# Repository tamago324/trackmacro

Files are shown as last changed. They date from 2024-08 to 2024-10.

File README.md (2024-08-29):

# trackmacro

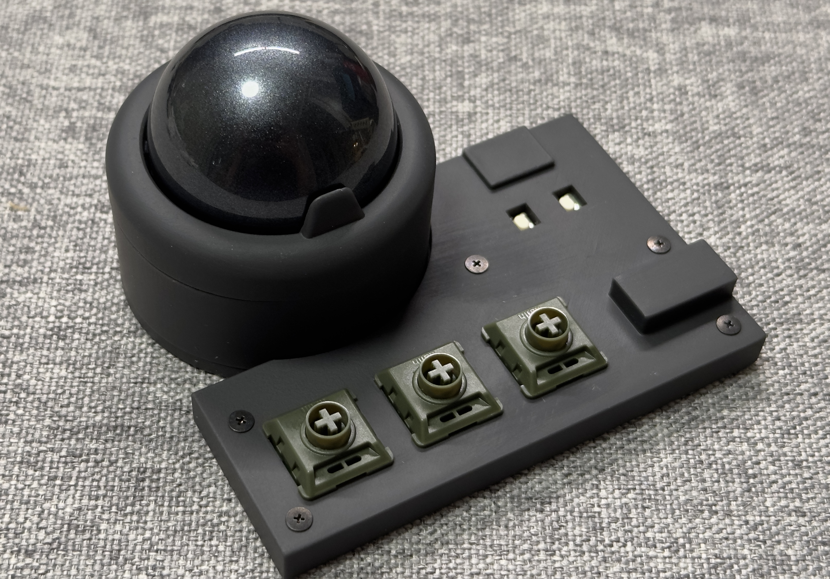
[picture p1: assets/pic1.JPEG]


> NOTE: KiCad 7 を使用しています

* [monkeypad/pmw3360-breakout](https://github.com/monkeypad/pmw3360-breakout) を使用したトラックボール付きのマクロパッド
* キーボードに載せるお試しで作ったもので、以下の要件を満たすものを作った
    * monkeypad/pmw3360-breakout を使う
        * ピンソケットを使用して、ブレークアウトボードは使い回せるようにする
    * RP2040-Zero を使う
        * PCBの裏にはんだ付けする
            * pmw3360-breakout のセンサの高さが一番高くなるため、裏に配置できた
    * 分割キーボードとして機能させる
    * Chocソケットを使う
        * そのためにトッププレートとボトムプレートをスペーサーとねじで止める構造にする
    * ボールケース
        * GameBall のボールを使ったケースを作成する (38mm)
        * 使い回せるような形状にする
        * ベアリングを使う
* [ファームウェア](https://github.com/tamago324/keyboard-firmwares/tree/master/keyboards/trackmacro)

## 使用している部品

|部品|リンク|備考|
|---|---|---|
|PMW3360ブレークアウトボード|[monkeypad/pmw3360-breakout](https://github.com/monkeypad/pmw3360-breakout)|Booth で購入したら、ピンヘッダーもついていたけど、おそらく[これ](https://www.hirosugi-net.co.jp/shop/c/c12103211/)|
|ピンソケット 8ピン|https://www.hirosugi-net.co.jp/shop/c/c12111211/|FSR-41085-08 / 8.5mmのものを使用する|
|スペーサー M2 5mm|https://www.hirosugi-net.co.jp/shop/c/c10141012/|トッププレートとボトムプレートを止めるために使用する|
|ねじ M2 3mm|https://wilco.jp/products/F/FX-EB.html#page3|トッププレートとボトムプレートを止めるために使用する|
|タッピングネジ M2 8mm|https://wilco.jp/products/F/FPP-N.html|FPP-0000N / ボトムプレートとボールケースを止めるために使用する。JLCPCBのレジンに使えるタッピングネジ|
|RP2040-Zero|||
|ダイオード|||
|chocソケット|||
|TRRSソケット|||

### ボールケース関連

|部品|リンク|備考|
|---|---|---|
|ベアリング|https://amzn.asia/d/8OED4Yl|DDL-520ZZW52 / 内径2mm、外形5mm、幅2.5mm|
|ねじ M2 8mm||なべ小ねじならなんでもOK (頭径3.5mm、高さ1.3)|
|ナット M2||1種のナットを使っている|
|磁石 3x2mm|https://amzn.asia/d/gBrgy0N|ボールケースの上下に瞬間接着剤 (アロンアルフア EXTRA 速効多用途) でつけている|

## 3Dプリント

* JLCPCB の3Dプリントを使う想定
* stl 内の stl ファイルを SLA(Resin) で発注する

## LICENSE

<br />この 作品 は <a rel="license" href="http://creativecommons.org/licenses/by-nc/4.0/">クリエイティブ・コモンズ 表示 - 非営利 4.0 国際 ライセンス</a>の下に提供されています。

> 表示 — あなたは 適切なクレジットを表示し、ライセンスへのリンクを提供し、変更があったらその旨を示さなければなりません。これらは合理的であればどのような方法で行っても構いませんが、許諾者があなたやあなたの利用行為を支持していると示唆するような方法は除きます。
>
> 非営利 — あなたは営利目的でこの資料を利用してはなりません。

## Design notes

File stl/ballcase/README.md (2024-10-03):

## ボールケース

* ベアリングの位置は20度
* STLファイル
  * ボールサイズ34mm
    * 34_bottom.stl
    * 34_top.stl
  * ボールサイズ36mm
    * 36_bottom.stl
    * 36_top.stl
  * ボールサイズ38mm
    * 38_bottom.stl
    * 38_top.stl

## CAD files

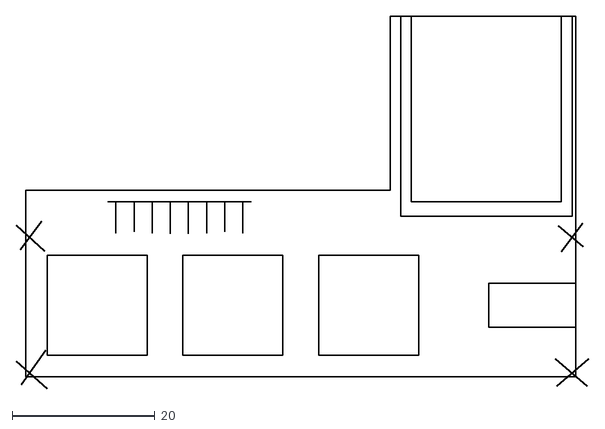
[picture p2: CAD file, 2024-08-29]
dxf/pcb_support.dxf
80.2 x 52.2

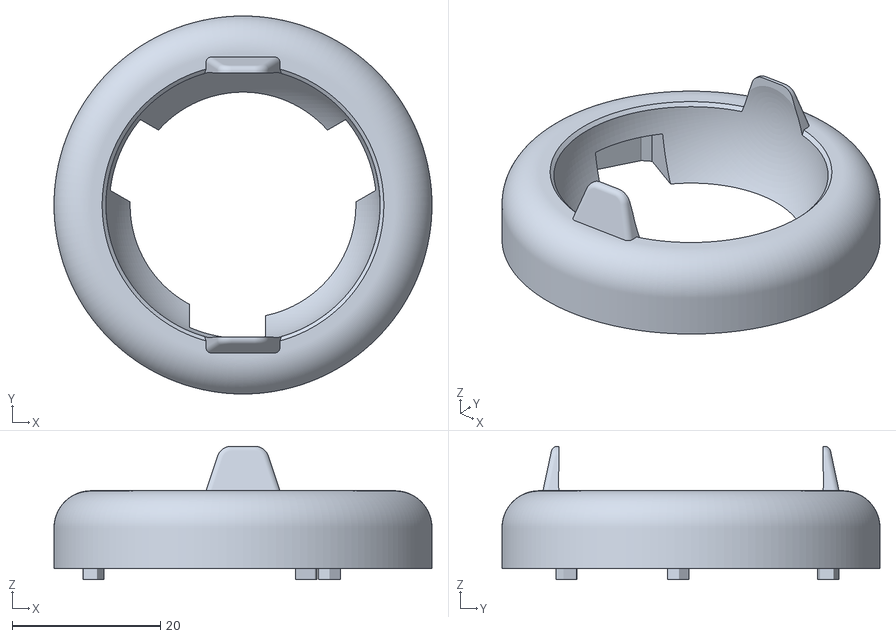
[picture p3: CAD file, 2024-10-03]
stl/ballcase/36_top.stl
51.0 x 51.0 x 18.0

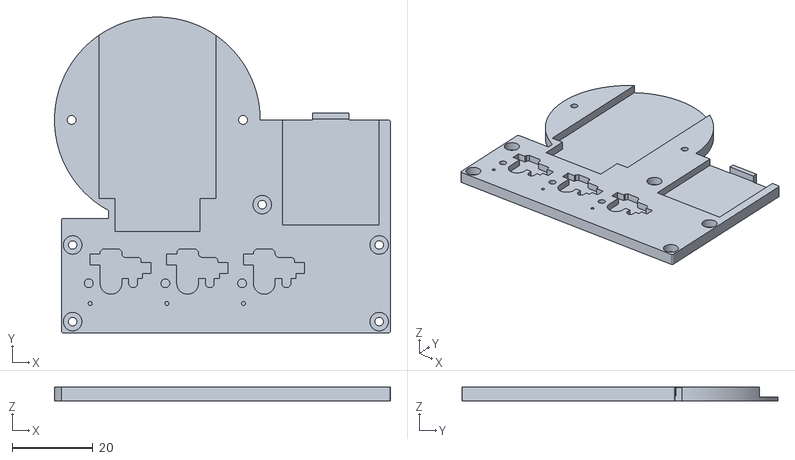
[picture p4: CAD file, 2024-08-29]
stl/trackmacro_case_bottom.stl
83.3 x 78.3 x 3.50

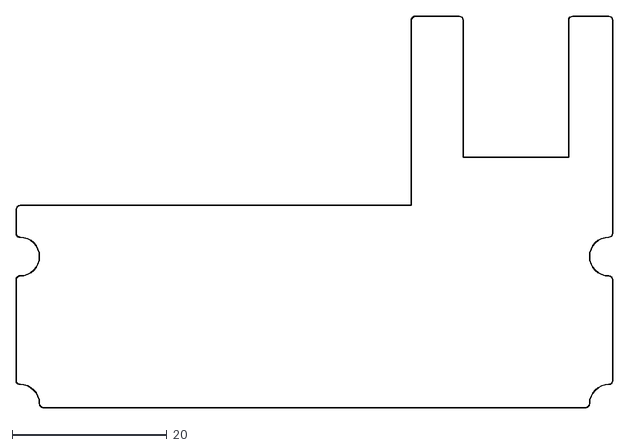
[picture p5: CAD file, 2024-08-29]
dxf/pcb_edge_filet.dxf
77.0 x 50.5

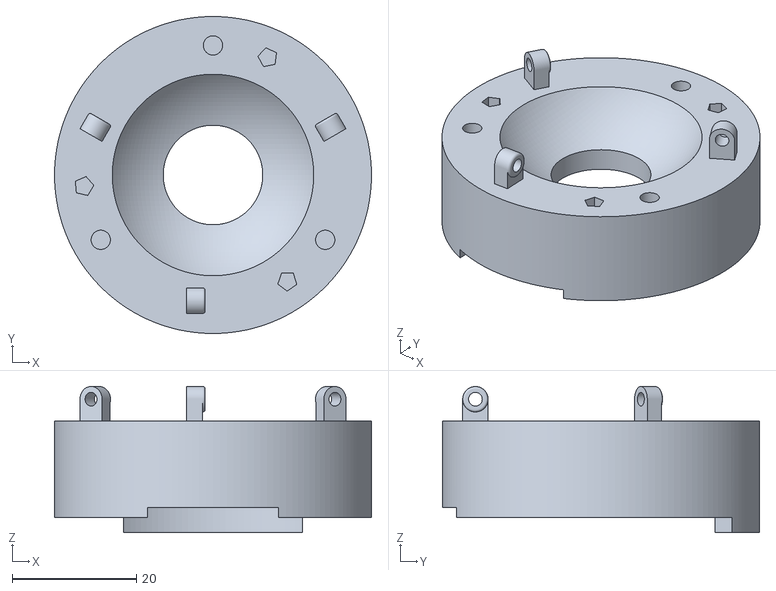
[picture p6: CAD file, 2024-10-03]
stl/ballcase/38_bottom.stl
51.0 x 51.0 x 23.5

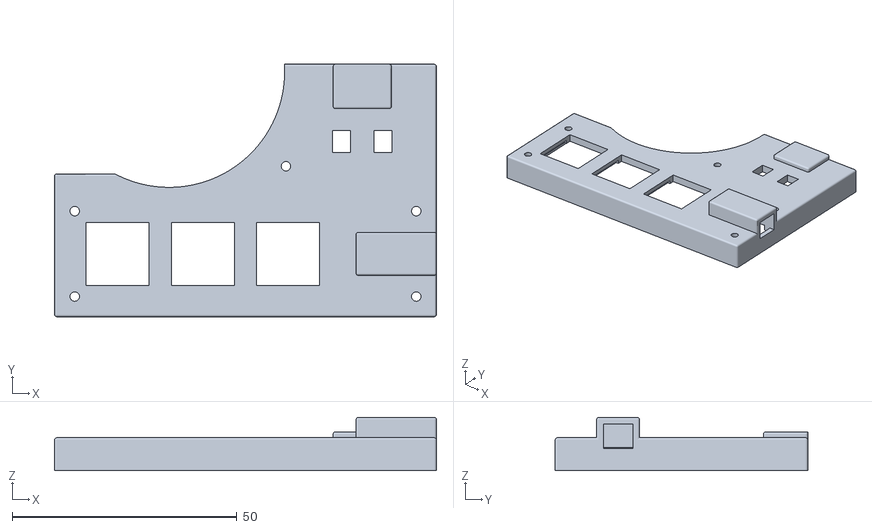
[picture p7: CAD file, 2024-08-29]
stl/trackmacro_case_top.stl
85.0 x 56.2 x 11.8

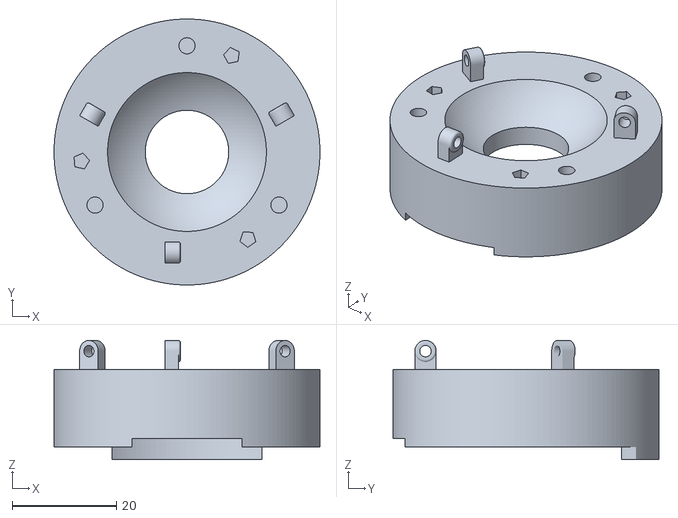
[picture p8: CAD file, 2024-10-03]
stl/ballcase/36_bottom.stl
51.0 x 51.0 x 22.8

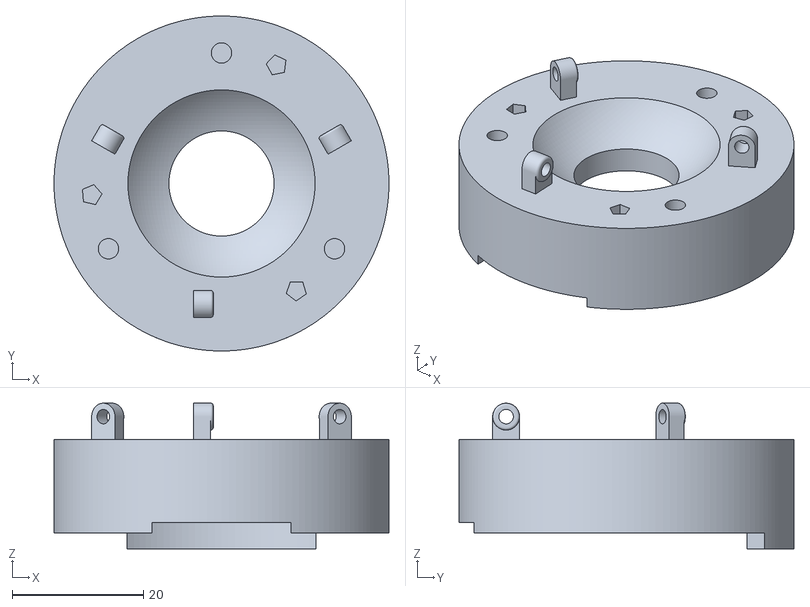
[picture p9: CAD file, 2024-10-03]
stl/ballcase/34_bottom.stl
51.0 x 51.0 x 22.2

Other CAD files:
stl/ballcase/34_top.stl
stl/ballcase/38_top.stl

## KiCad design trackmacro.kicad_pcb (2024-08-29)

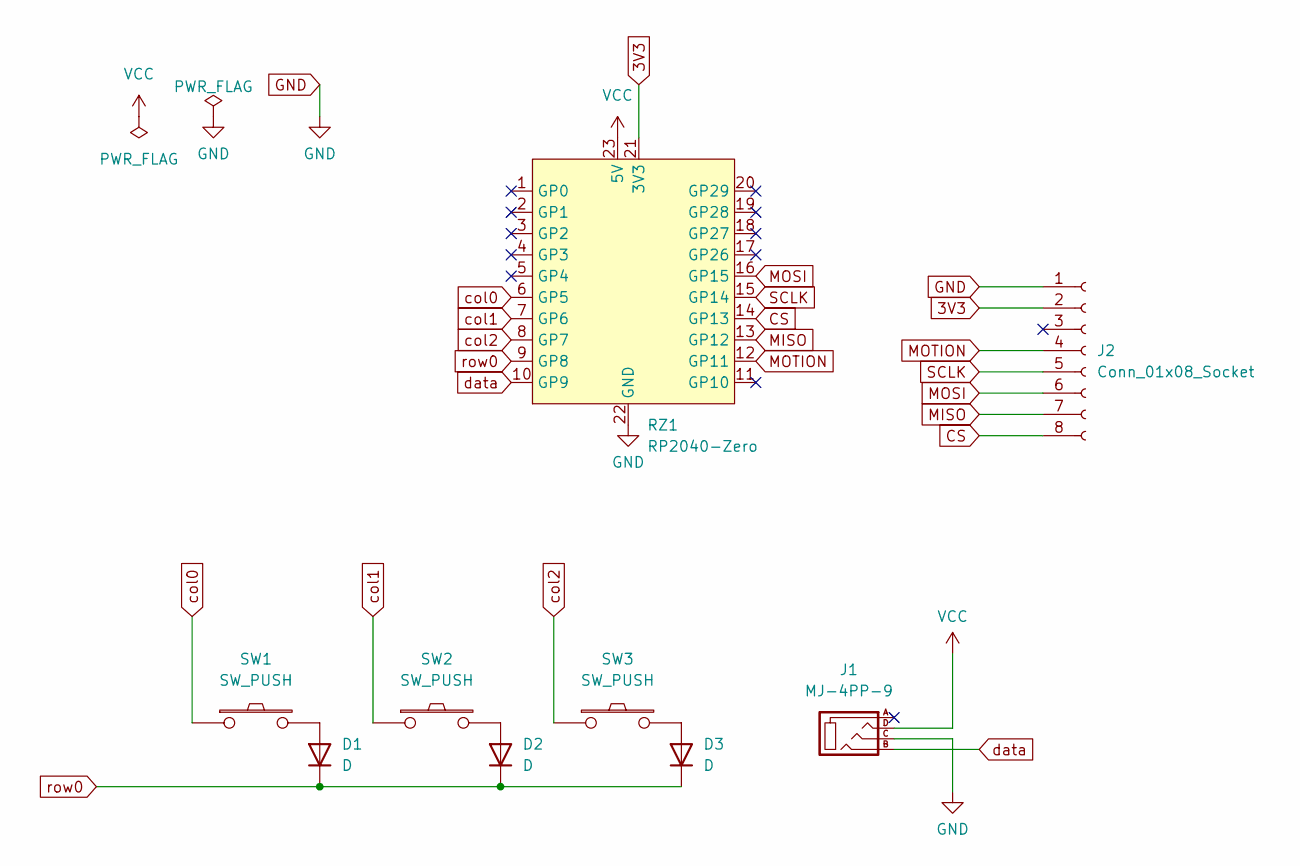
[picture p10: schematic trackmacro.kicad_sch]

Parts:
D1, D2, D3: D; D3_SMD
J1: MJ-4PP-9
J2: Conn_01x08_Socket; PinSocket_1x08_P2.54mm
RZ1: RP2040-Zero
SW1, SW2, SW3: SW_PUSH; Kailh_socket_PG1350

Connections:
3V3: J2.2, RZ1.21 (3V3)
CS: J2.8, RZ1.14 (GP13)
GND: J1.C, J2.1, RZ1.22 (GND)
MISO: J2.7, RZ1.13 (GP12)
MOSI: J2.6, RZ1.16 (GP15)
MOTION: J2.4, RZ1.12 (GP11)
unnamed: D1.2 (A), SW1.2
unnamed: D2.2 (A), SW2.2
unnamed: D3.2 (A), SW3.2
SCLK: J2.5, RZ1.15 (GP14)
VCC: J1.D, RZ1.23 (5V)
col0: RZ1.6 (GP5), SW1.1
col1: RZ1.7 (GP6), SW2.1
col2: RZ1.8 (GP7), SW3.1
data: J1.B, RZ1.10 (GP9)
row0: D1.1 (K), D2.1 (K), D3.1 (K), RZ1.9 (GP8)

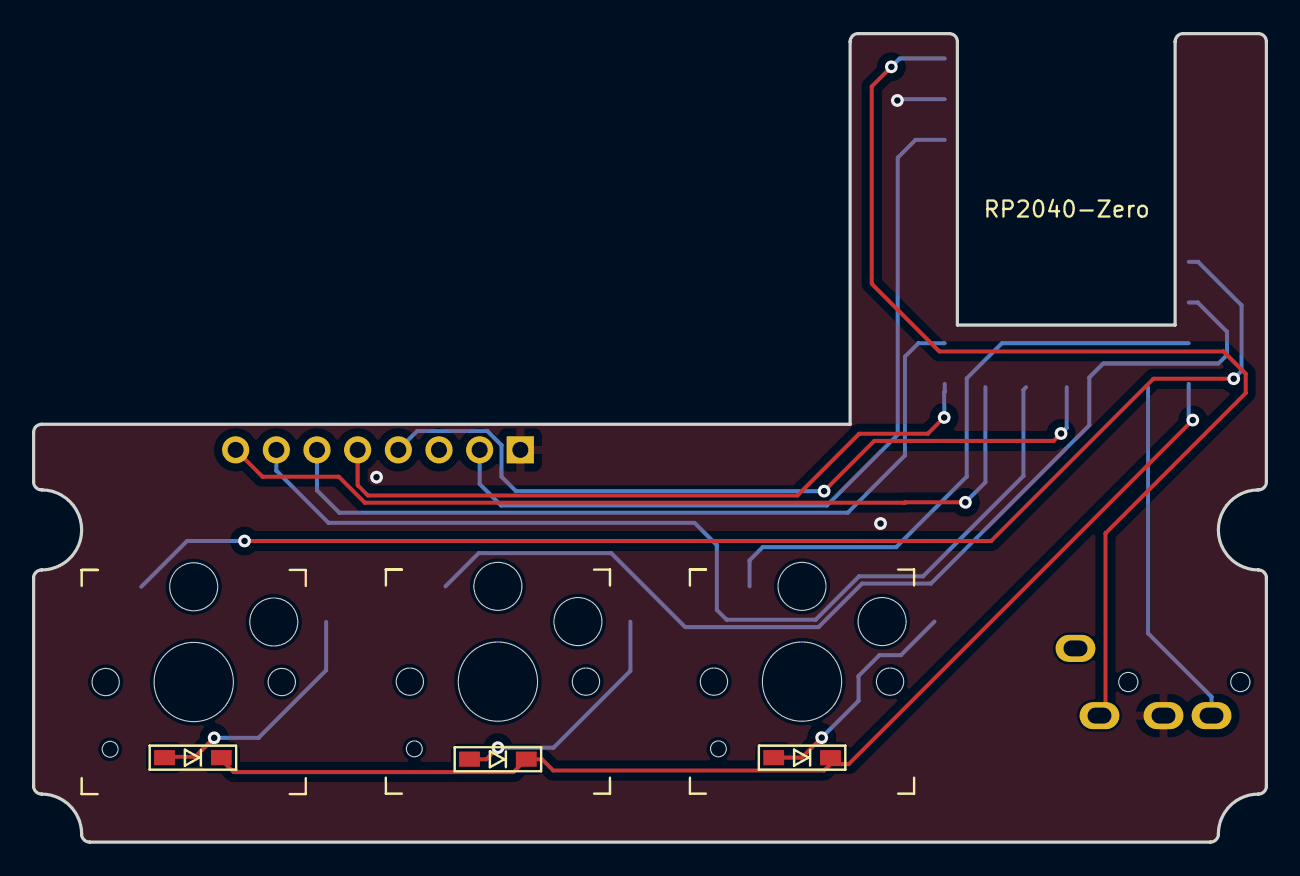
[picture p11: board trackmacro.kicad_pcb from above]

Board: 2 copper layers, 77.0 x 50.5 mm, 9 parts (0 on the bottom side), 16 nets.

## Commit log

2024-08-29 LICENSE 追加
2024-08-29 写真追加
2024-08-29 NOTE 追加
2024-08-29 ファームウェアのリンクを追加
2024-08-29 GameBall のボール用の説明を追記
2024-10-03 ベアリングの位置は20度で、34,36,38 のボールケースを追加
    [34_bottom.stl, 34_top.stl, 36_bottom.stl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]

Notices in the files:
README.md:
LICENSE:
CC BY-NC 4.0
